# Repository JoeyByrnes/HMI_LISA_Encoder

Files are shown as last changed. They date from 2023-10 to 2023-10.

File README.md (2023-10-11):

# HMI_LISA_Encoder
Design Files for an AS5147U encoder for the RoboDesign Lab HMI Actuators.
<br>
- All outputs support 14 bits and can be used simultaneously. 
- All signals/power routed to conenctors are protected from ESD.

- Output Options:
    - Differential ABI
    - Single-Ended ABI
    - Absolute SPI
<br>

- Power Input Options:
    - 3.3v
    - 5v
<br>

<br>
<p align="center">
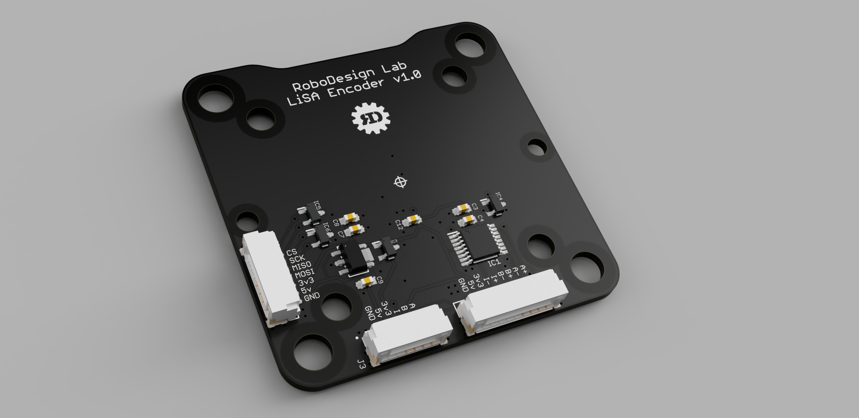
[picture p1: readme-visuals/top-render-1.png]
  
</p>

<p align="center">
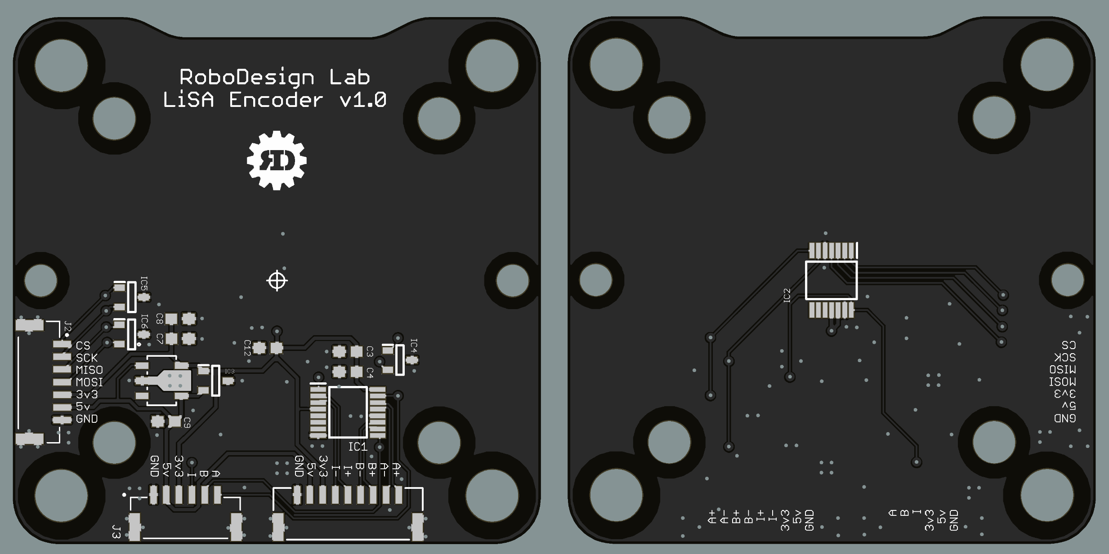
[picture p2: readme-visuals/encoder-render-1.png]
  
</p>

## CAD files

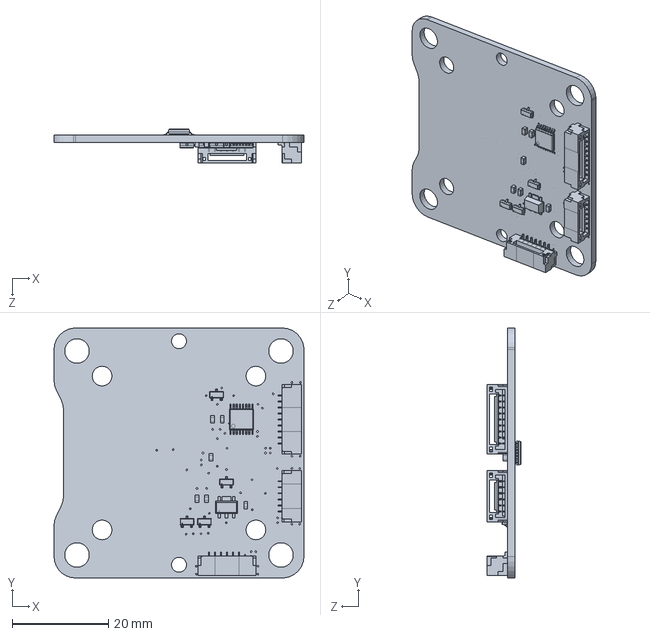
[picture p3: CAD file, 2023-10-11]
3D/hmi-lisa-encoder.SLDPRT
52.0 x 52.0 x 7.02 mm

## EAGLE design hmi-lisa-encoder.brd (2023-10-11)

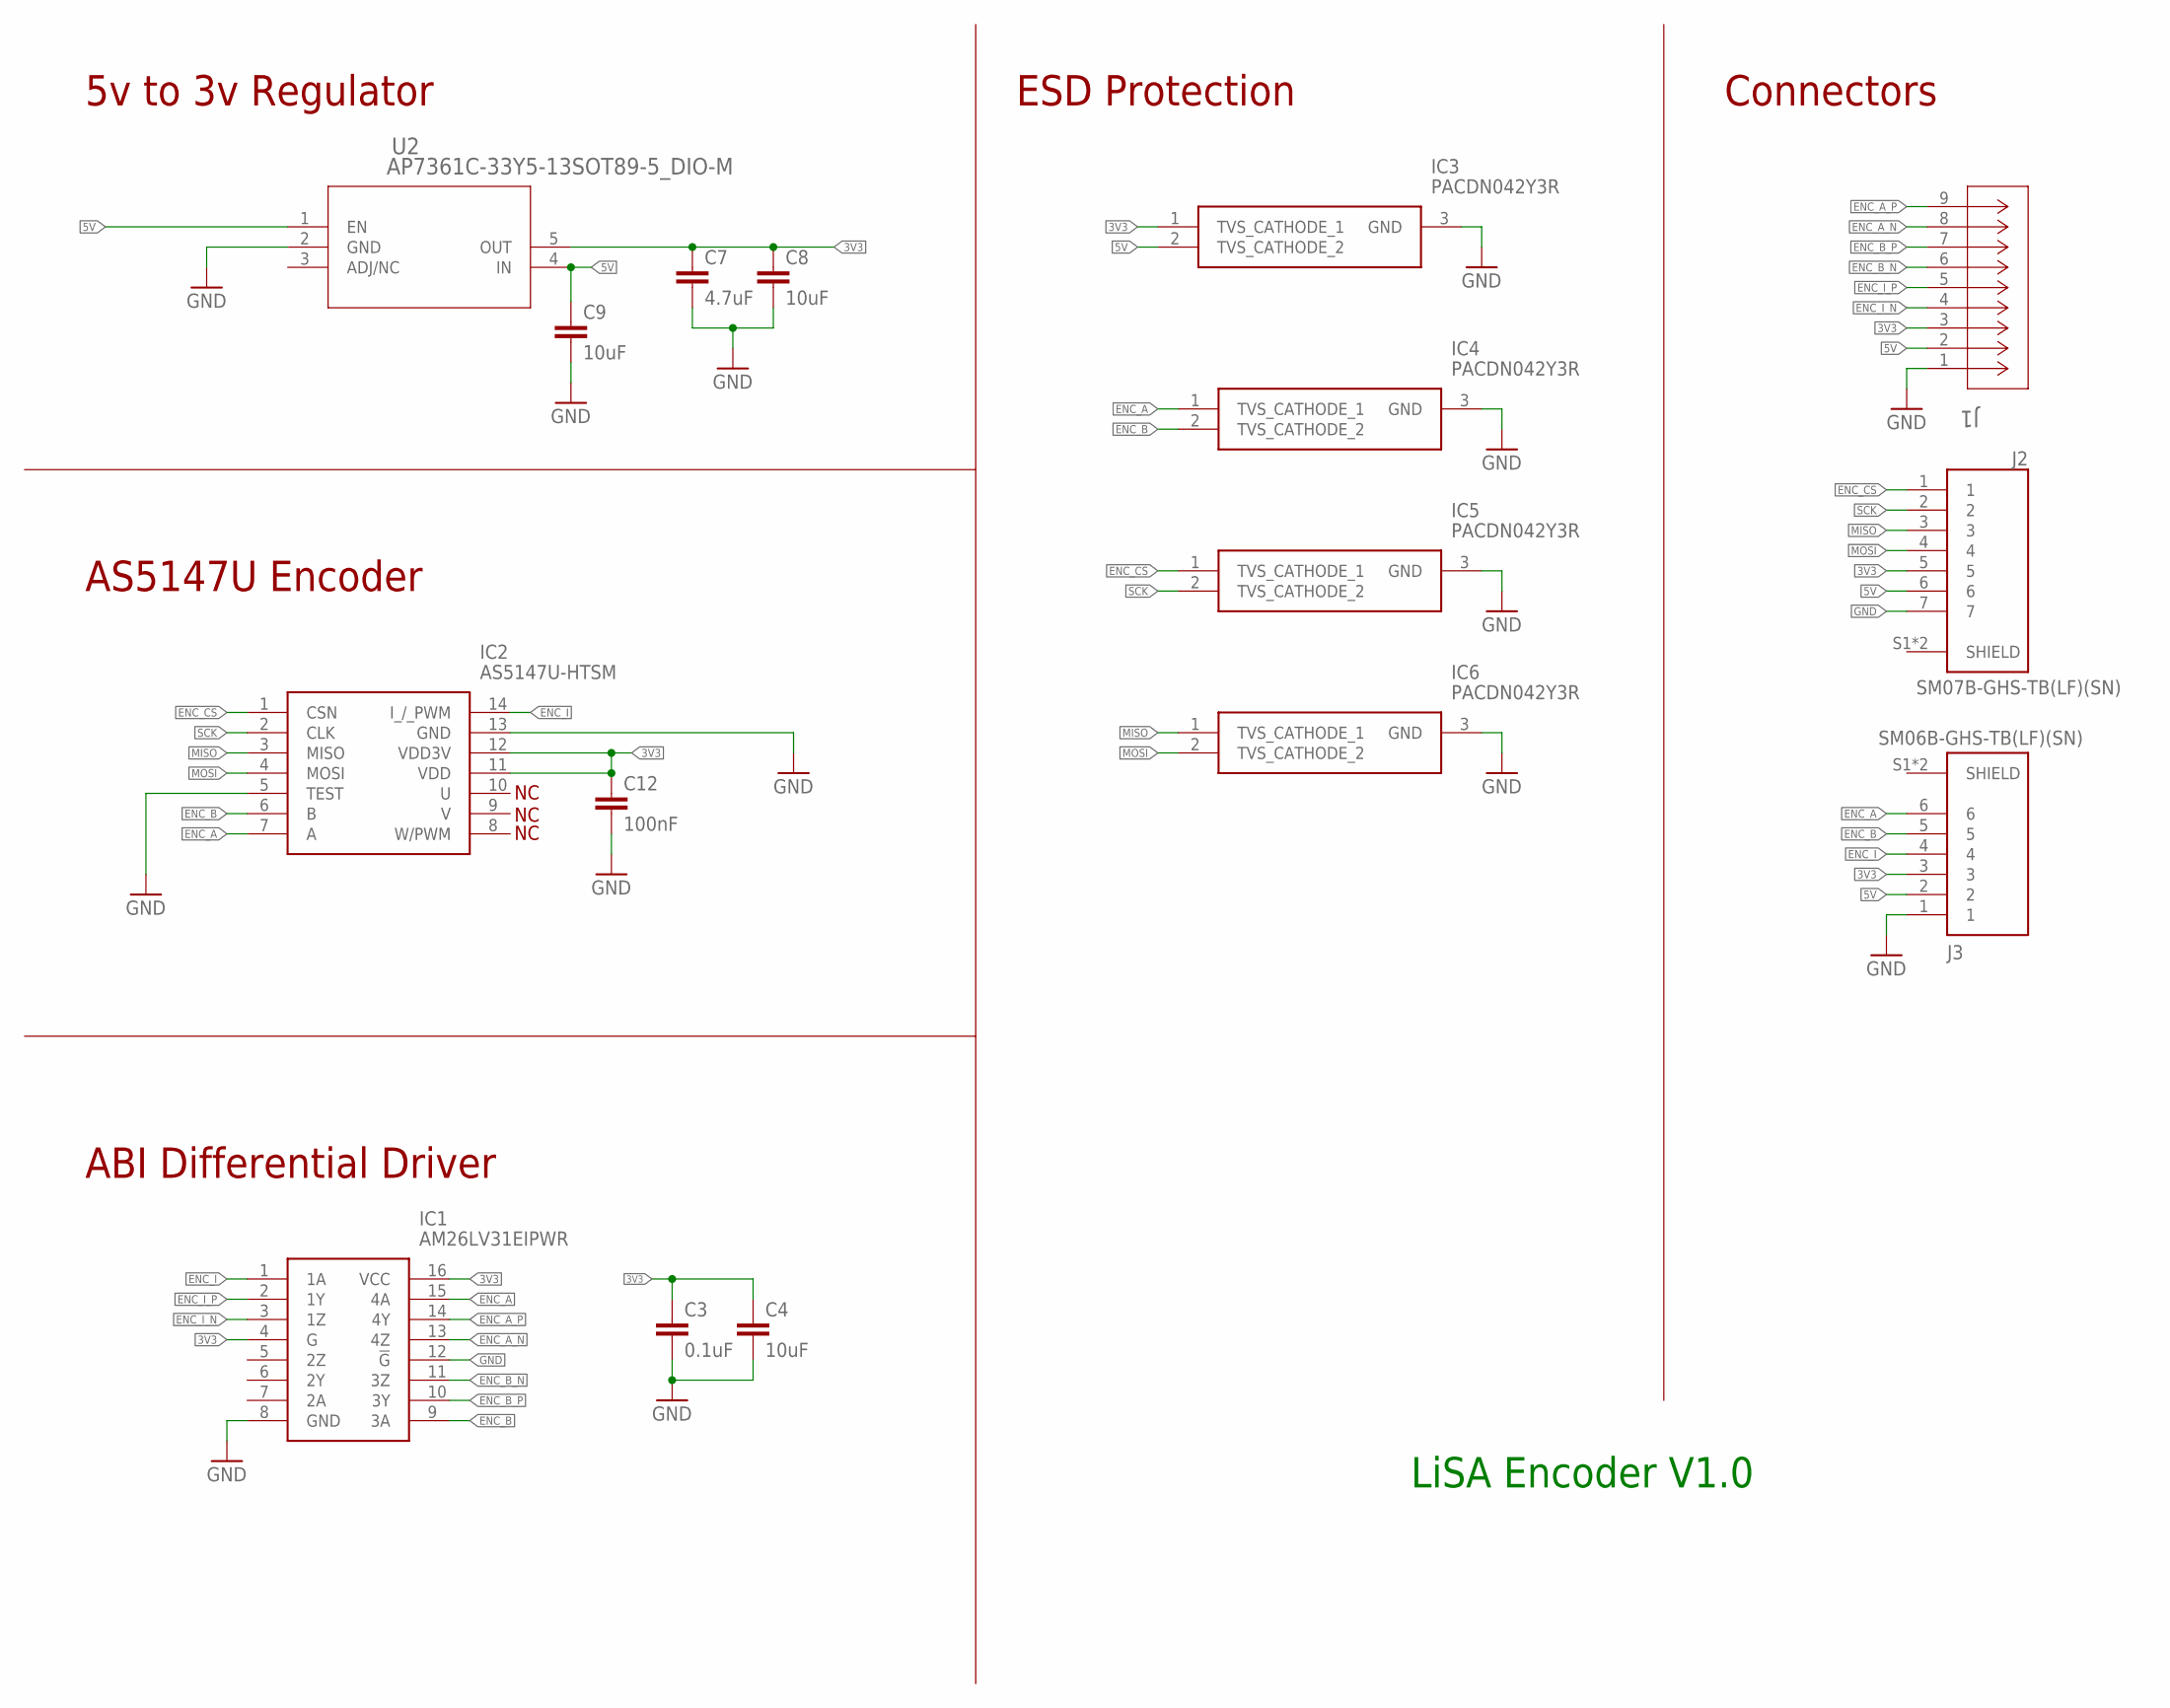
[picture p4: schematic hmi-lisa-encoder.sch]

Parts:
C3: 0.1uF; C0603
C4, C8, C9: 10uF; C0603
C7: 4.7uF; C0603
C12: 100nF; C0603
IC1: AM26LV31EIPWR; SOP65P640X120-16N
IC2: AS5147U-HTSM; SOP65P640X120-14N
IC3, IC4, IC5, IC6: PACDN042Y3R; SOT96P237X111-3N
J1: SM09B-GHS-TB(LF)(SN); CONN_SM09B-GHS-TB_JST
J2: SM07B-GHS-TB(LF)(SN); JST_SM07B-GHS-TB(LF)(SN)
J3: SM06B-GHS-TB(LF)(SN); JST_SM06B-GHS-TB(LF)(SN)
U2: AP7361C-33Y5-13SOT89-5_DIO-M; SOT89-5_DIO-M

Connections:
3V3: C3.1, C4.1, C7.1, C8.1, C12.1, IC1.4 (G), IC1.16 (VCC), IC2.11 (VDD), IC2.12 (VDD3V), IC3.1 (TVS_CATHODE_1), J1.3, J2.5, J3.3, U2.5 (OUT)
5V: C9.1, IC3.2 (TVS_CATHODE_2), J1.2, J2.6, J3.2, U2.1 (EN), U2.4 (IN)
ENC_A: IC1.15 (4A), IC2.7 (A), IC4.1 (TVS_CATHODE_1), J3.6
ENC_A_N: IC1.13 (4Z), J1.8
ENC_A_P: IC1.14 (4Y), J1.9
ENC_B: IC1.9 (3A), IC2.6 (B), IC4.2 (TVS_CATHODE_2), J3.5
ENC_B_N: IC1.11 (3Z), J1.6
ENC_B_P: IC1.10 (3Y), J1.7
ENC_CS: IC2.1 (CSN), IC5.1 (TVS_CATHODE_1), J2.1
ENC_I: IC1.1 (1A), IC2.14 (I_/_PWM), J3.4
ENC_I_N: IC1.3 (1Z), J1.4
ENC_I_P: IC1.2 (1Y), J1.5
GND: C3.2, C4.2, C7.2, C8.2, C9.2, C12.2, IC1.8 (GND), IC1.12 (!G), IC2.5 (TEST), IC2.13 (GND), IC3.3 (GND), IC4.3 (GND), IC5.3 (GND), IC6.3 (GND), J1.1, J2.7, J3.1, U2.2 (GND)
MISO: IC2.3 (MISO), IC6.1 (TVS_CATHODE_1), J2.3
MOSI: IC2.4 (MOSI), IC6.2 (TVS_CATHODE_2), J2.4
SCK: IC2.2 (CLK), IC5.2 (TVS_CATHODE_2), J2.2
SHIELD: J2.S1 (SHIELD), J2.S2 (SHIELD)

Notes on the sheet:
5v to 3v Regulator
LiSA Encoder V1.0
ESD Protection
AS5147U Encoder
Connectors
ABI Differential Driver

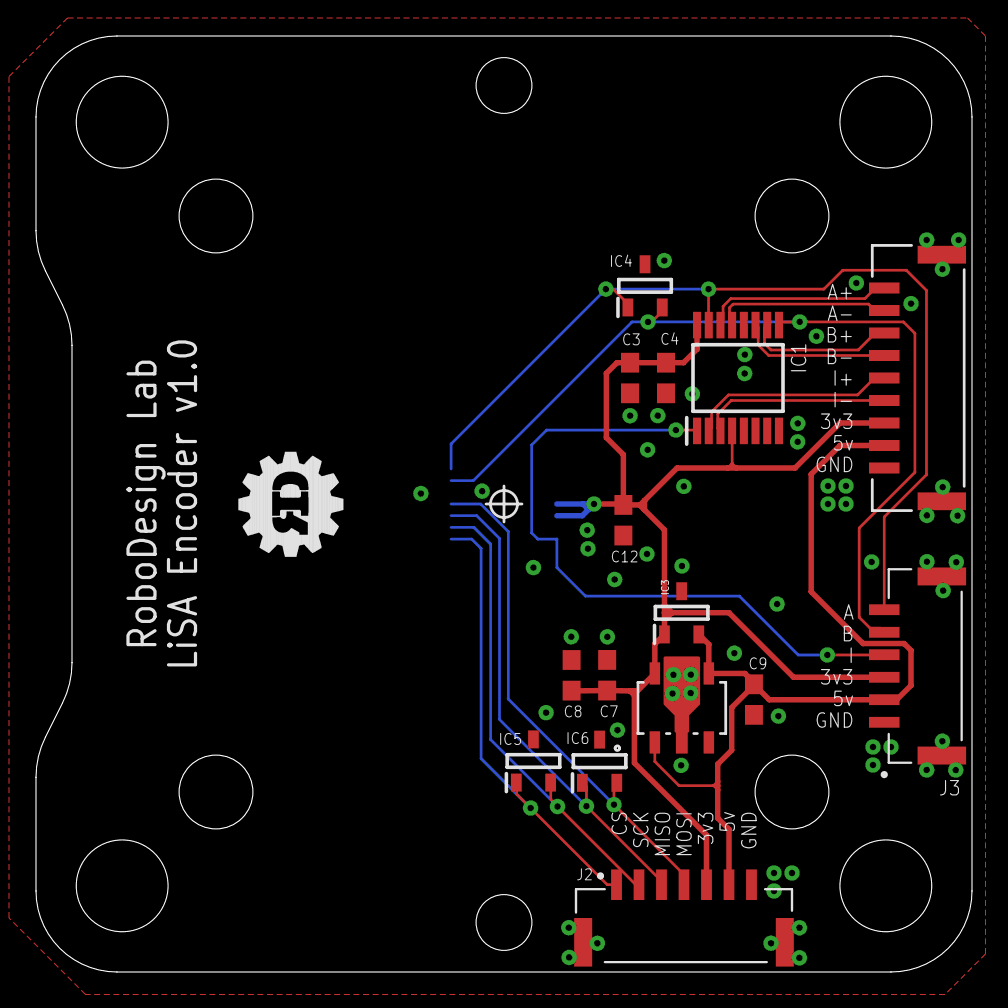
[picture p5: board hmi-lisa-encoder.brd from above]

Board: 2 copper layers, 52.0 x 52.0 mm, 16 parts (1 on the bottom side), 17 nets.

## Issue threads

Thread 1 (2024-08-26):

AS5147U c/c++ drivers source code

AlbertEEWork, 2024-08-26:
Hi, have you implemented any drivers for this sensor.

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
AlbertEEWork, 2024-08-27:
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

I don't know if you had malicious intend, but there's no reason to distribute source code through an installer

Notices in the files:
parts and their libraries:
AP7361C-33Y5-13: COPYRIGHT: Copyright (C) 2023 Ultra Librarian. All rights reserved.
